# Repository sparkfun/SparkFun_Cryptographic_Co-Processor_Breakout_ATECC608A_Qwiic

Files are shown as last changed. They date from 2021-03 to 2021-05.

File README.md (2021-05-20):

SparkFun Cryptographic Co-Processor Breakout - ATECC608A (Qwiic)
========================================

SparkFun Cryptographic Breakout

[*SparkFun Cryptographic Co-Processor Breakout - ATECC608A (Qwiic) (DEV-18077)*](https://www.sparkfun.com/products/18077)

The SparkFun ATECC608A Cryptographic Co-processor Breakout allows you to add strong security to your IoT node, edge device, or embedded system. This includes asymmetric authentication, symmetric AES-128 encryption/decryption, and much more. As stated above, the ATECC608A has limited Arduino support and the complete datasheet is under NDA with Microchip.

This breakout board includes two Qwiic ports for plug and play functionality. Utilizing our handy Qwiic system, no soldering is required to connect it to the rest of your system. However, we still have broken out 0.1"-spaced pins in case you prefer to use a breadboard. The ATECC608A chip is capable of many cryptographic processes, including, but not limited to:

* Creating and securely storing unique asymmetric key pairs based on Elliptic Curve Cryptography (FIPS186-3).
* AES-128: Encrypt/Decrypt, Galois Field Multiply for GCM
* Creating and verifying 64-byte digital signatures (from 32-bytes of message data).
* Creating a shared secret key on a public channel via Elliptic Curve Diffie-Hellman Algorithm.
* SHA-256 & HMAC Hash including off-chip context save/restore
* Internal high quality FIPS random number generator.
* Embedded in the chip is a 10Kb EEPROM array that can be used for storing keys, certificates, data, consumption logging, and security configurations. Access to the sections of memory can then be restricted and the configuration locked to prevent changes. Each ATECC608A Breakout ships with a guaranteed unique 72-bit serial number and includes several security features to prevent physical attacks on the device itself, or logical attacks on the data transmitted between the device.

A summary datasheet for the ATECC608A is available [here](https://cdn.sparkfun.com/assets/d/5/c/c/a/ATECC608A-CryptoAuthentication-Device-Summary-Data-Sheet-DS40001977B.pdf). The full datasheet is under NDA with Microchip. You will need to contact them for access to the entire datasheet. Meanwhile, the ArduinoATECCX08 Library currently only supports the ATECC608A with SAMD21 Arduino boards

Repository Contents
-------------------

* **/Documentation** - Data sheets, additional product information
* **/Hardware** - Eagle design files (.brd, .sch)
* **/Hardware/Production** - Production panel files (.brd)

Documentation
--------------
* **[ArduinoECCX08 Arduino Library](https://github.com/arduino-libraries/ArduinoECCX08)** - Arduino library for the ATECCX08A.
* **[CryptoAuthLib - ](https://github.com/MicrochipTech/cryptoauthlib)** - Microchip CryptoAuthentication Library (includes Python support).

Product Versions
----------------
* [DEV-18077](https://www.sparkfun.com/products/18077)- Initial Release
* [SPX-15838](https://www.sparkfun.com/products/15838)- SparkX Release

License Information
-------------------

This product is _**open source**_! 

Please review the LICENSE.md file for license information. 

If you have any questions or concerns on licensing, please contact technical support through the [SparkFun forum](https://forum.sparkfun.com/index.php).

Please use, reuse, and modify these files as you see fit. Please maintain attribution to SparkFun Electronics and release any derivative under the same license.

Distributed as-is; no warranty is given.

- Your friends at SparkFun.

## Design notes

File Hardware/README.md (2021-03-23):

SparkFun <PRODUCT NAME> Design Files
=====================================

The .sch and .brd files hare are Eagle CAD schematic and PCB design files from SparkFun Electronics.
A freeware version of Eagle can be found [here](https://www.autodesk.com/products/eagle/free-download).

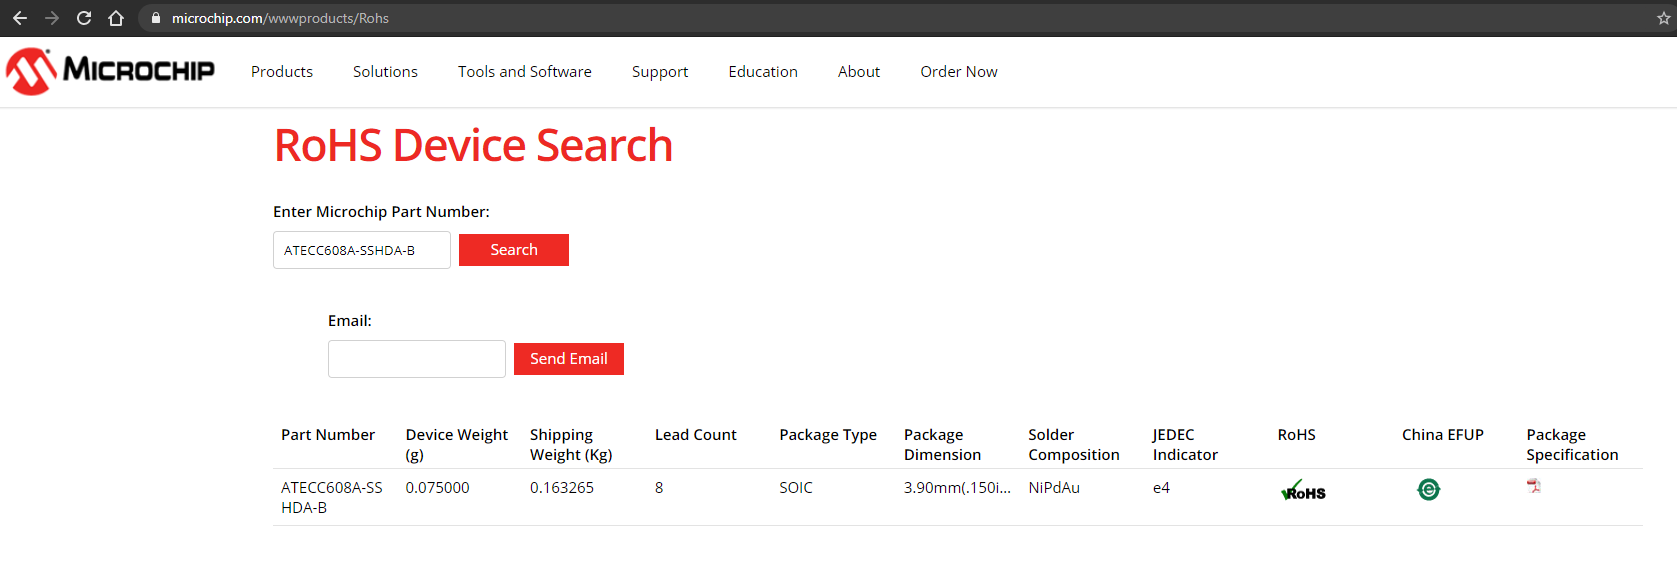
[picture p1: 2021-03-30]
Documentation/RoHS_COMPLIANCE_screenshot_microchip.png

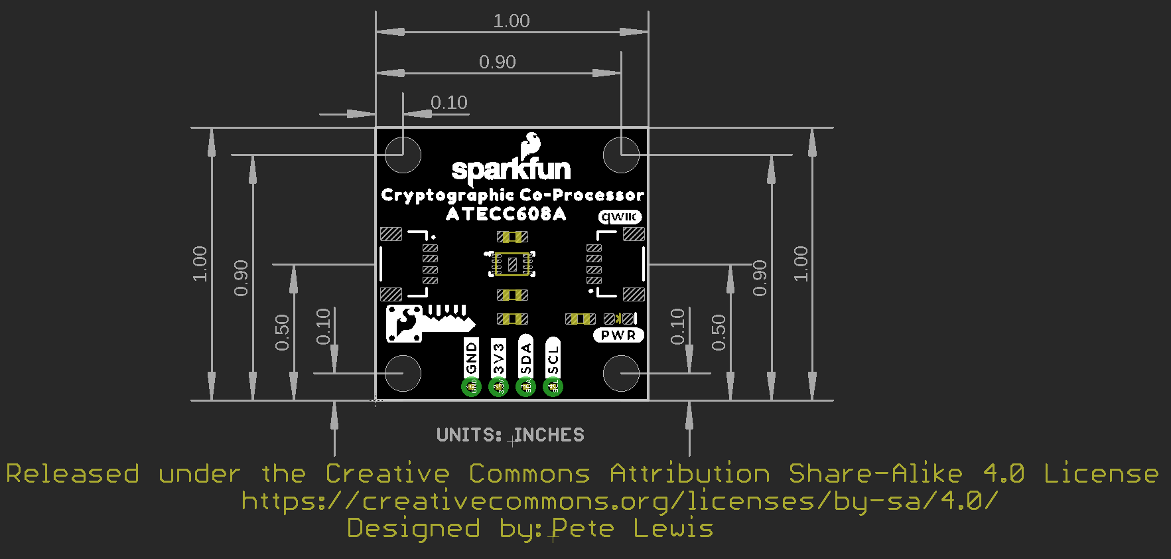
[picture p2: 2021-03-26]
Documentation/SparkFun_Cryptographic_Co-processor_ATECC608A_Dimensions.png

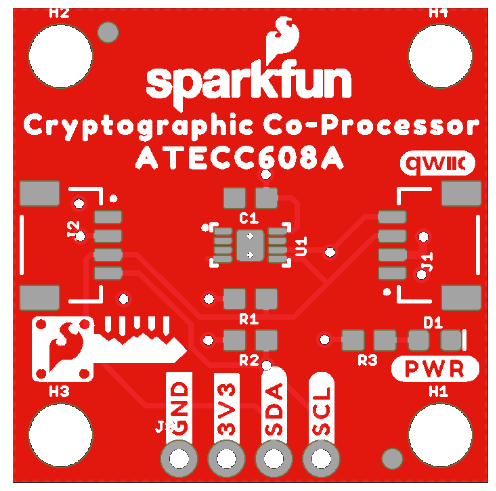
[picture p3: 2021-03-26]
Documentation/board_preview.png

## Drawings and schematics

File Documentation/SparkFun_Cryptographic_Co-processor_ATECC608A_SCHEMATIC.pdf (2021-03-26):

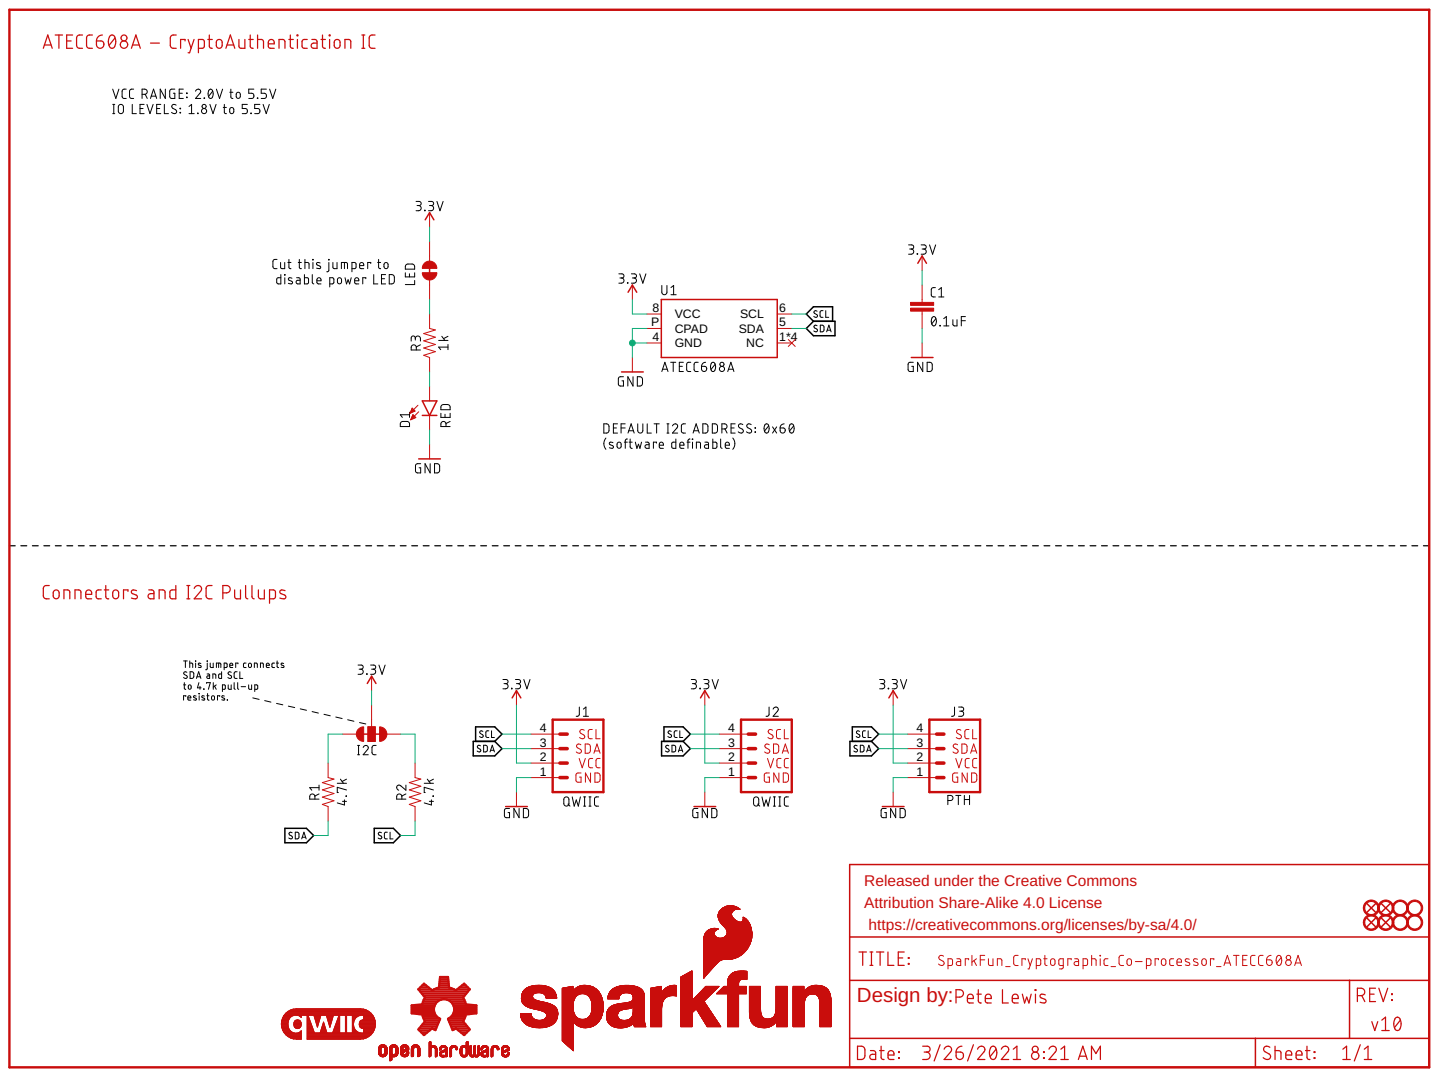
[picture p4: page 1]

Released under the Creative Commons
Attribution Share-Alike 4.0 License
https://creativecommons.org/licenses/by-sa/4.0/

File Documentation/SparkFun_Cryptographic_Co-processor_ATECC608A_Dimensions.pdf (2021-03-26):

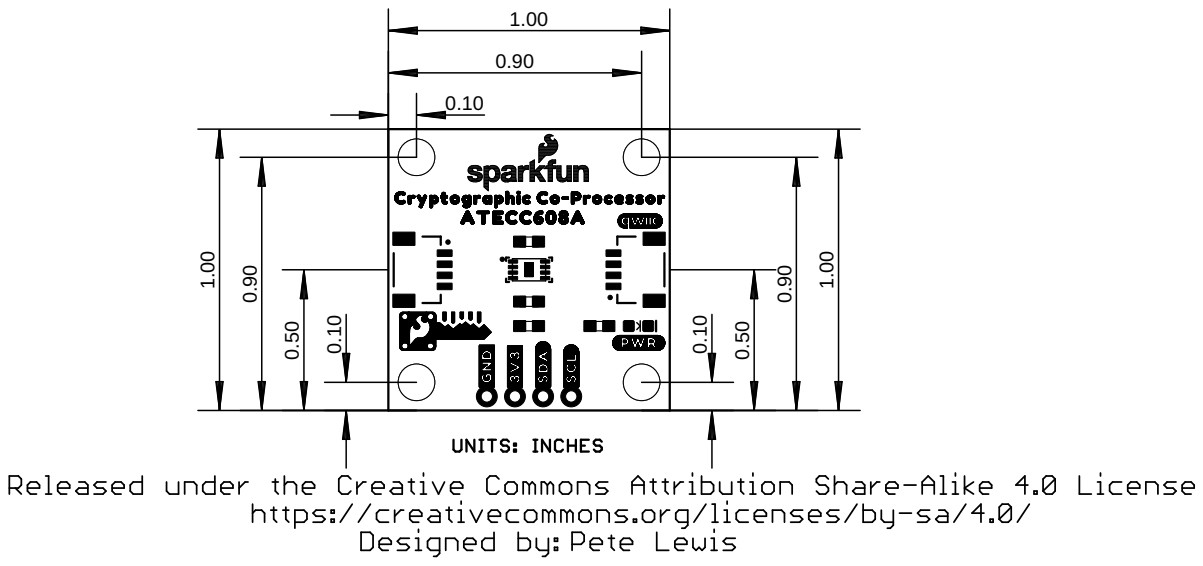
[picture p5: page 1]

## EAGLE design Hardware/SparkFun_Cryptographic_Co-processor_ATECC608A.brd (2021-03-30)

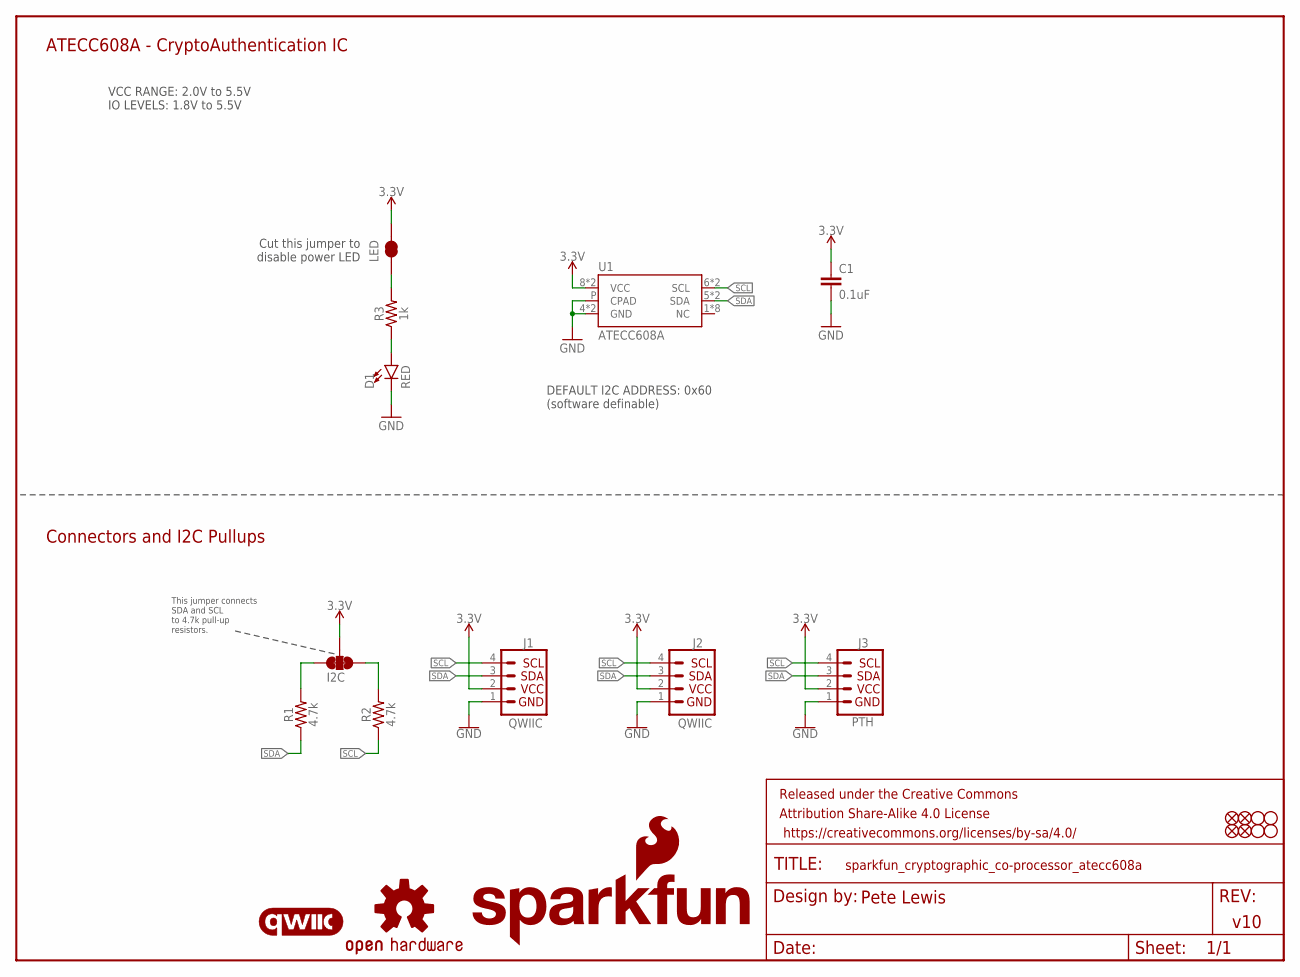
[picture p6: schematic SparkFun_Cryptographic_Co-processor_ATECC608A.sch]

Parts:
C1: 0.1uF; 0603
D1: RED; LED-0603
FD1, FD2, FD3, FD4: FIDUCIAL1X2; FIDUCIAL-1X2
FRAME1: FRAME-LETTER; CREATIVE_COMMONS
H1, H2, H3, H4: STAND-OFF
I2C: JUMPER-SMT_3_2-NC_TRACE_SILK; SMT-JUMPER_3_2-NC_TRACE_SILK
J1, J2: QWIIC; JST04_1MM_RA
J3: PTH; 1X04_NO_SILK
LED: JUMPER-SMT_2_NC_TRACE_SILK; SMT-JUMPER_2_NC_TRACE_SILK
LOGO1: SFE_LOGO_NAME_FLAME.1_INCH; SFE_LOGO_NAME_FLAME_.1
LOGO3: QWIIC_LOGO_4MM; QWIIC_4MM
LOGO4: OSHW-LOGOS; OSHW-LOGO-S
R1, R2: 4.7k; 0603
R3: 1k; 0603
U1: ATECC608A; DUAL_UDFN_2X3MM_SOIC-8

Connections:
3.3V: C1.1, I2C.2, J1.2, J2.2, J3.2, LED.2, U1.8 (VCC), U1.8S (VCC)
GND: C1.2, D1.C, J1.1, J2.1, J3.1, U1.4 (GND), U1.4S (GND), U1.P (CPAD)
unnamed: D1.A, R3.1
unnamed: I2C.3, R1.2
unnamed: I2C.1, R2.2
unnamed: LED.1, R3.2
SCL: J1.4, J2.4, J3.4, R2.1, U1.6 (SCL), U1.6S (SCL)
SDA: J1.3, J2.3, J3.3, R1.1, U1.5 (SDA), U1.5S (SDA)

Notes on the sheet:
This jumper connects SDA and SCL to 4.7k pull-up resistors.
v10
Pete Lewis
ATECC608A - CryptoAuthentication IC
VCC RANGE: 2.0V to 5.5V IO LEVELS: 1.8V to 5.5V
Connectors and I2C Pullups
Cut this jumper to disable power LED
DEFAULT I2C ADDRESS: 0x60 (software definable)

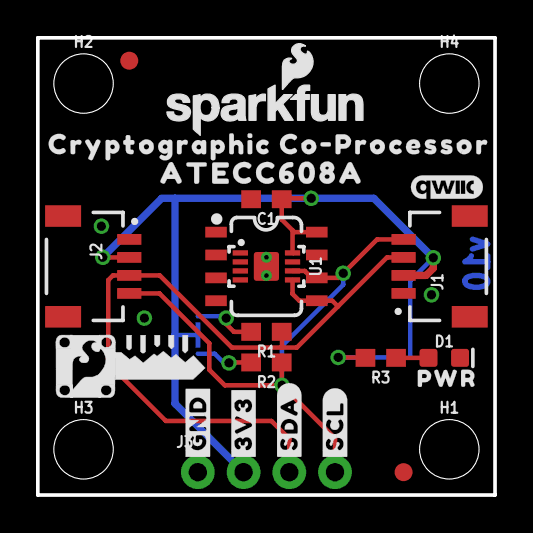
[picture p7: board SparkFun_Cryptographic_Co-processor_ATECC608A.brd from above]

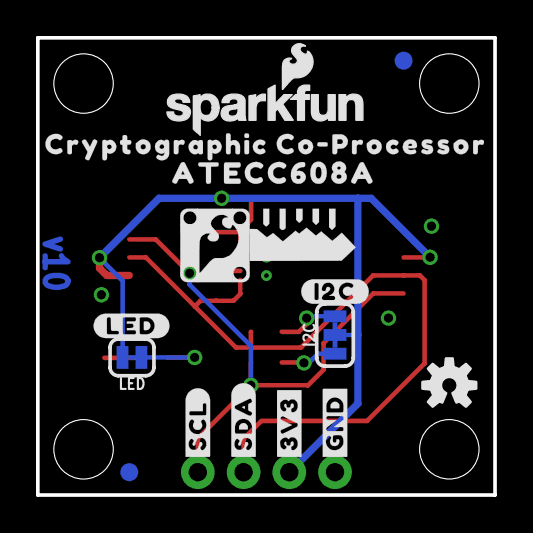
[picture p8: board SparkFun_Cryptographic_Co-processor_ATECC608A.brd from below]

Board: 2 copper layers, 25.4 x 25.4 mm, 41 parts (15 on the bottom side), 8 nets.

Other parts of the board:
LOGO2: SFE_LOGO_NAME_FLAME.1_INCH; SFE_LOGO_NAME_FLAME_.1
U$1: #I2C#0
U$2, U$13: #SCL#0
U$3: #LED#0
U$4, U$17: #SDA#0
U$5, U$7: ATECC608A0
U$6, U$20: #3V3#0
U$8: CRYPTO_COPROCESSOR_LOGO_LARGE
U$9, U$19: CRYPTOGRAPHIC_CO#PROCESSOR0
U$10: CRYPTO_COPROCESSOR_LOGO_SMALL
U$11: PWR0
U$21, U$23: #GND#0

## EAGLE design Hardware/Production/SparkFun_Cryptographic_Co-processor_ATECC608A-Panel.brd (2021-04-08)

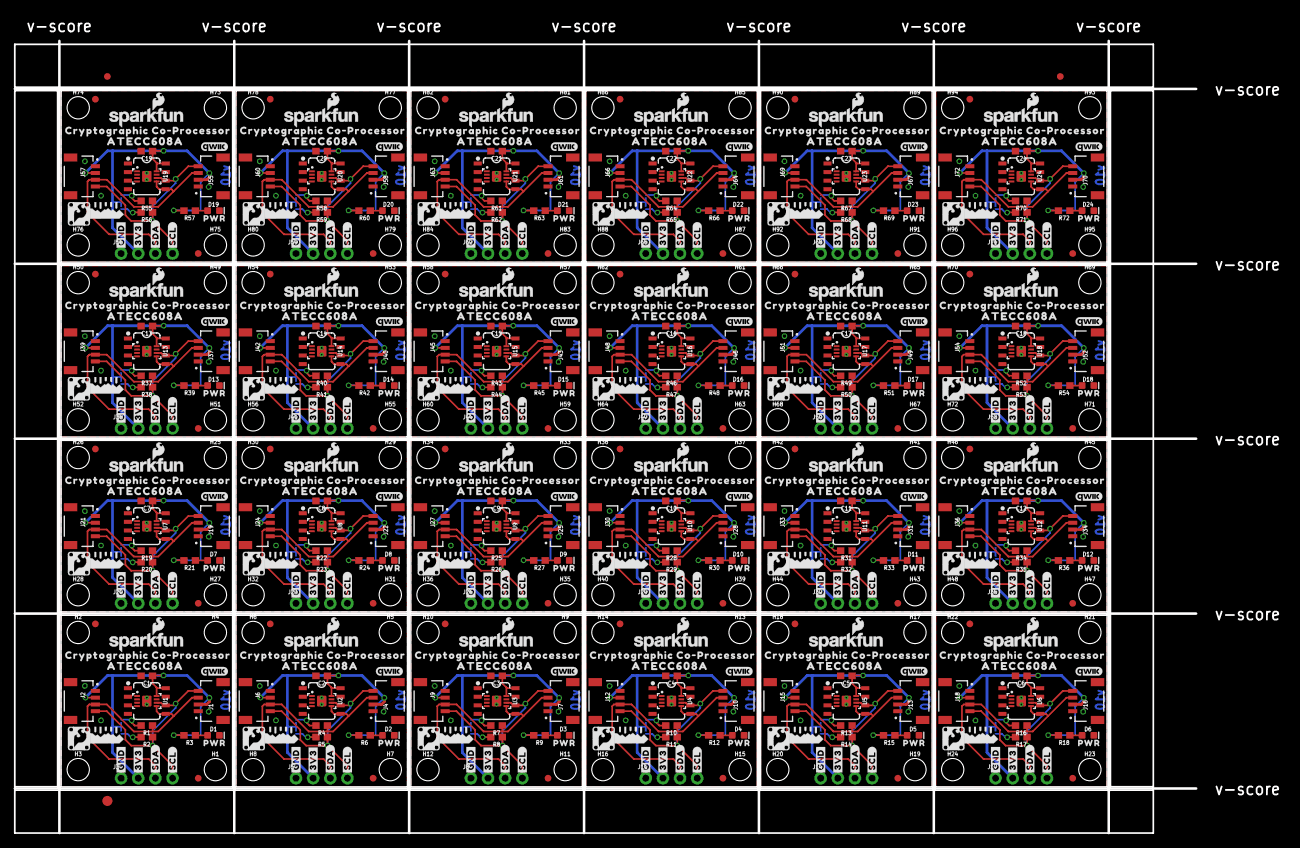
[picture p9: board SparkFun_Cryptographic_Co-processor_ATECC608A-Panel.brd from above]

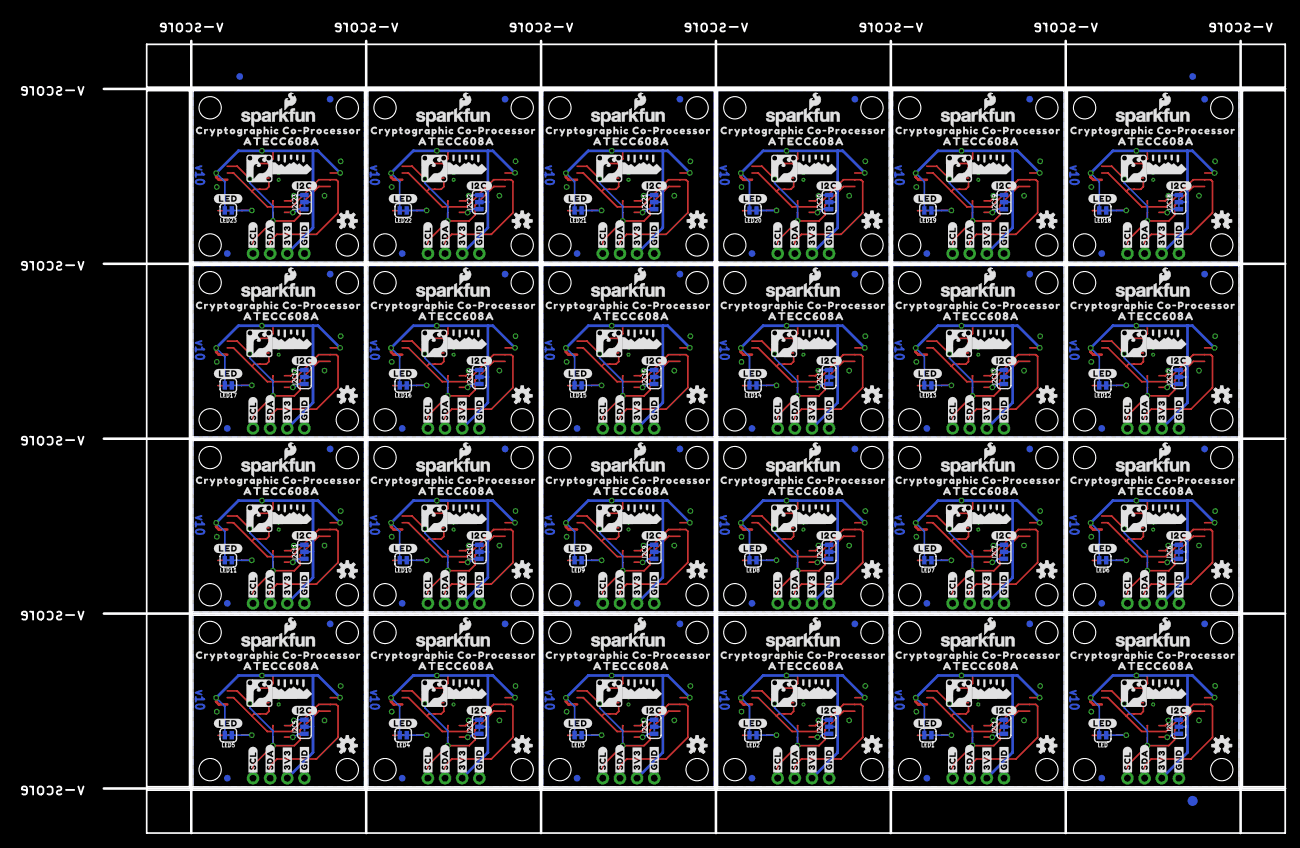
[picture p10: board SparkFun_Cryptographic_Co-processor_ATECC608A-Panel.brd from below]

Board: 2 copper layers, 175.0 x 117.3 mm, 966 parts (363 on the bottom side), 192 nets.

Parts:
C1, C2, C3, C4, C5, C6, C7, C8, C9, C10, C11, C12, C13, C14, C15, C16, C17, C18, C19, C20, C21, C22, C23, C24: 0.1uF; 0603
D1, D2, D3, D4, D5, D6, D7, D8, D9, D10, D11, D12, D13, D14, D15, D16, D17, D18, D19, D20, D21, D22, D23, D24: RED; LED-0603
E$1, E$2, E$3, E$4: FIDUCIAL-1X2
E$5, E$6: FIDUCIAL-1.5X3
FD1, FD2, FD3, FD4, FD5, FD6, FD7, FD8, FD9, FD10, FD11, FD12, FD13, FD14, FD15, FD16, FD17, FD18, FD19, FD20, FD21, FD22, FD23, FD24, FD25, FD26, FD27, FD28, FD29, FD30, FD31, FD32, FD33, FD34, FD35, FD36, FD37, FD38, FD39, FD40, FD41, FD42, FD43, FD44, FD45, FD46, FD47, FD48, FD49, FD50, FD51, FD52, FD53, FD54, FD55, FD56, FD57, FD58, FD59, FD60, FD61, FD62, FD63, FD64, FD65, FD66, FD67, FD68, FD69, FD70, FD71, FD72, FD73, FD74, FD75, FD76, FD77, FD78, FD79, FD80, FD81, FD82, FD83, FD84, FD85, FD86, FD87, FD88, FD89, FD90, FD91, FD92, FD93, FD94, FD95, FD96: FIDUCIAL1X2; FIDUCIAL-1X2
H1, H2, H3, H4, H5, H6, H7, H8, H9, H10, H11, H12, H13, H14, H15, H16, H17, H18, H19, H20, H21, H22, H23, H24, H25, H26, H27, H28, H29, H30, H31, H32, H33, H34, H35, H36, H37, H38, H39, H40, H41, H42, H43, H44, H45, H46, H47, H48, H49, H50, H51, H52, H53, H54, H55, H56, H57, H58, H59, H60, H61, H62, H63, H64, H65, H66, H67, H68, H69, H70, H71, H72, H73, H74, H75, H76, H77, H78, H79, H80, H81, H82, H83, H84, H85, H86, H87, H88, H89, H90, H91, H92, H93, H94, H95, H96: STAND-OFF
I2C, I2C1, I2C2, I2C3, I2C4, I2C5, I2C6, I2C7, I2C8, I2C9, I2C10, I2C11, I2C12, I2C13, I2C14, I2C15, I2C16, I2C17, I2C18, I2C19, I2C20, I2C21, I2C22, I2C23: SMT-JUMPER_3_2-NC_TRACE_SILK
J1, J2, J4, J6, J7, J9, J10, J12, J13, J15, J16, J18, J19, J21, J22, J24, J25, J27, J28, J30, J31, J33, J34, J36, J37, J39, J40, J42, J43, J45, J46, J48, J49, J51, J52, J54, J55, J57, J58, J60, J61, J63, J64, J66, J67, J69, J70, J72: QWIIC; JST04_1MM_RA
J3, J5, J8, J11, J14, J17, J20, J23, J26, J29, J32, J35, J38, J41, J44, J47, J50, J53, J56, J59, J62, J65, J68, J71: PTH; 1X04_NO_SILK
LED, LED1, LED2, LED3, LED4, LED5, LED6, LED7, LED8, LED9, LED10, LED11, LED12, LED13, LED14, LED15, LED16, LED17, LED18, LED19, LED20, LED21, LED22, LED23: SMT-JUMPER_2_NC_TRACE_SILK
LOGO1, LOGO2, LOGO6, LOGO7, LOGO10, LOGO11, LOGO14, LOGO15, LOGO18, LOGO19, LOGO22, LOGO23, LOGO26, LOGO27, LOGO30, LOGO31, LOGO34, LOGO35, LOGO38, LOGO39, LOGO42, LOGO43, LOGO46, LOGO47, LOGO50, LOGO51, LOGO54, LOGO55, LOGO58, LOGO59, LOGO62, LOGO63, LOGO66, LOGO67, LOGO70, LOGO71, LOGO74, LOGO75, LOGO78, LOGO79, LOGO82, LOGO83, LOGO86, LOGO87, LOGO90, LOGO91, LOGO94, LOGO95: SFE_LOGO_NAME_FLAME.1_INCH; SFE_LOGO_NAME_FLAME_.1
LOGO3, LOGO8, LOGO12, LOGO16, LOGO20, LOGO24, LOGO28, LOGO32, LOGO36, LOGO40, LOGO44, LOGO48, LOGO52, LOGO56, LOGO60, LOGO64, LOGO68, LOGO72, LOGO76, LOGO80, LOGO84, LOGO88, LOGO92, LOGO96: QWIIC_LOGO_4MM; QWIIC_4MM
LOGO4, LOGO5, LOGO9, LOGO13, LOGO17, LOGO21, LOGO25, LOGO29, LOGO33, LOGO37, LOGO41, LOGO45, LOGO49, LOGO53, LOGO57, LOGO61, LOGO65, LOGO69, LOGO73, LOGO77, LOGO81, LOGO85, LOGO89, LOGO93: OSHW-LOGOS; OSHW-LOGO-S
R1, R2, R4, R5, R7, R8, R10, R11, R13, R14, R16, R17, R19, R20, R22, R23, R25, R26, R28, R29, R31, R32, R34, R35, R37, R38, R40, R41, R43, R44, R46, R47, R49, R50, R52, R53, R55, R56, R58, R59, R61, R62, R64, R65, R67, R68, R70, R71: 4.7k; 0603
R3, R6, R9, R12, R15, R18, R21, R24, R27, R30, R33, R36, R39, R42, R45, R48, R51, R54, R57, R60, R63, R66, R69, R72: 1k; 0603
U1, U2, U3, U4, U5, U6, U7, U8, U9, U10, U11, U12, U13, U14, U15, U16, U17, U18, U19, U20, U21, U22, U23, U24: ATECC608A; DUAL_UDFN_2X3MM_SOIC-8
U$1, U$29, U$46, U$63, U$80, U$97, U$114, U$131, U$148, U$165, U$182, U$199, U$216, U$233, U$250, U$267, U$284, U$301, U$318, U$335, U$352, U$369, U$386, U$403: #I2C#0
U$2, U$13, U$15, U$24, U$37, U$41, U$54, U$58, U$71, U$75, U$88, U$92, U$105, U$109, U$122, U$126, U$139, U$143, U$156, U$160, U$173, U$177, U$190, U$194, U$207, U$211, U$224, U$228, U$241, U$245, U$258, U$262, U$275, U$279, U$292, U$296, U$309, U$313, U$326, U$330, U$343, U$347, U$360, U$364, U$377, U$381, U$394, U$398: #SCL#0
U$3, U$28, U$45, U$62, U$79, U$96, U$113, U$130, U$147, U$164, U$181, U$198, U$215, U$232, U$249, U$266, U$283, U$300, U$317, U$334, U$351, U$368, U$385, U$402: #LED#0
U$4, U$16, U$17, U$25, U$38, U$42, U$55, U$59, U$72, U$76, U$89, U$93, U$106, U$110, U$123, U$127, U$140, U$144, U$157, U$161, U$174, U$178, U$191, U$195, U$208, U$212, U$225, U$229, U$242, U$246, U$259, U$263, U$276, U$280, U$293, U$297, U$310, U$314, U$327, U$331, U$344, U$348, U$361, U$365, U$378, U$382, U$395, U$399: #SDA#0
U$5, U$7, U$30, U$31, U$47, U$48, U$64, U$65, U$81, U$82, U$98, U$99, U$115, U$116, U$132, U$133, U$149, U$150, U$166, U$167, U$183, U$184, U$200, U$201, U$217, U$218, U$234, U$235, U$251, U$252, U$268, U$269, U$285, U$286, U$302, U$303, U$319, U$320, U$336, U$337, U$353, U$354, U$370, U$371, U$387, U$388, U$404, U$405: ATECC608A0
U$6, U$18, U$20, U$26, U$39, U$43, U$56, U$60, U$73, U$77, U$90, U$94, U$107, U$111, U$124, U$128, U$141, U$145, U$158, U$162, U$175, U$179, U$192, U$196, U$209, U$213, U$226, U$230, U$243, U$247, U$260, U$264, U$277, U$281, U$294, U$298, U$311, U$315, U$328, U$332, U$345, U$349, U$362, U$366, U$379, U$383, U$396, U$400: #3V3#0
U$8, U$32, U$49, U$66, U$83, U$100, U$117, U$134, U$151, U$168, U$185, U$202, U$219, U$236, U$253, U$270, U$287, U$304, U$321, U$338, U$355, U$372, U$389, U$406: CRYPTO_COPROCESSOR_LOGO_LARGE
U$9, U$12, U$14, U$19, U$35, U$36, U$52, U$53, U$69, U$70, U$86, U$87, U$103, U$104, U$120, U$121, U$137, U$138, U$154, U$155, U$171, U$172, U$188, U$189, U$205, U$206, U$222, U$223, U$239, U$240, U$256, U$257, U$273, U$274, U$290, U$291, U$307, U$308, U$324, U$325, U$341, U$342, U$358, U$359, U$375, U$376, U$392, U$393: CRYPTOGRAPHIC_CO#PROCESSOR0
U$10, U$33, U$50, U$67, U$84, U$101, U$118, U$135, U$152, U$169, U$186, U$203, U$220, U$237, U$254, U$271, U$288, U$305, U$322, U$339, U$356, U$373, U$390, U$407: CRYPTO_COPROCESSOR_LOGO_SMALL
U$11, U$34, U$51, U$68, U$85, U$102, U$119, U$136, U$153, U$170, U$187, U$204, U$221, U$238, U$255, U$272, U$289, U$306, U$323, U$340, U$357, U$374, U$391, U$408: PWR0
U$21, U$22, U$23, U$27, U$40, U$44, U$57, U$61, U$74, U$78, U$91, U$95, U$108, U$112, U$125, U$129, U$142, U$146, U$159, U$163, U$176, U$180, U$193, U$197, U$210, U$214, U$227, U$231, U$244, U$248, U$261, U$265, U$278, U$282, U$295, U$299, U$312, U$316, U$329, U$333, U$346, U$350, U$363, U$367, U$380, U$384, U$397, U$401: #GND#0

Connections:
3.3V: C1.1, I2C.2, J1.2, J2.2, J3.2, LED.2, U1.8, U1.8S
3.3V1: C2.1, I2C1.2, J4.2, J5.2, J6.2, LED1.2, U2.8, U2.8S
3.3V2: C3.1, I2C2.2, J7.2, J8.2, J9.2, LED2.2, U3.8, U3.8S
3.3V3: C4.1, I2C3.2, J10.2, J11.2, J12.2, LED3.2, U4.8, U4.8S
3.3V4: C5.1, I2C4.2, J13.2, J14.2, J15.2, LED4.2, U5.8, U5.8S
3.3V5: C6.1, I2C5.2, J16.2, J17.2, J18.2, LED5.2, U6.8, U6.8S
3.3V6: C7.1, I2C6.2, J19.2, J20.2, J21.2, LED6.2, U7.8, U7.8S
3.3V7: C8.1, I2C7.2, J22.2, J23.2, J24.2, LED7.2, U8.8, U8.8S
3.3V8: C9.1, I2C8.2, J25.2, J26.2, J27.2, LED8.2, U9.8, U9.8S
3.3V9: C10.1, I2C9.2, J28.2, J29.2, J30.2, LED9.2, U10.8, U10.8S
3.3V10: C11.1, I2C10.2, J31.2, J32.2, J33.2, LED10.2, U11.8, U11.8S
3.3V11: C12.1, I2C11.2, J34.2, J35.2, J36.2, LED11.2, U12.8, U12.8S
3.3V12: C13.1, I2C12.2, J37.2, J38.2, J39.2, LED12.2, U13.8, U13.8S
3.3V13: C14.1, I2C13.2, J40.2, J41.2, J42.2, LED13.2, U14.8, U14.8S
3.3V14: C15.1, I2C14.2, J43.2, J44.2, J45.2, LED14.2, U15.8, U15.8S
3.3V15: C16.1, I2C15.2, J46.2, J47.2, J48.2, LED15.2, U16.8, U16.8S
3.3V16: C17.1, I2C16.2, J49.2, J50.2, J51.2, LED16.2, U17.8, U17.8S
3.3V17: C18.1, I2C17.2, J52.2, J53.2, J54.2, LED17.2, U18.8, U18.8S
3.3V18: C19.1, I2C18.2, J55.2, J56.2, J57.2, LED18.2, U19.8, U19.8S
3.3V19: C20.1, I2C19.2, J58.2, J59.2, J60.2, LED19.2, U20.8, U20.8S
3.3V20: C21.1, I2C20.2, J61.2, J62.2, J63.2, LED20.2, U21.8, U21.8S
3.3V21: C22.1, I2C21.2, J64.2, J65.2, J66.2, LED21.2, U22.8, U22.8S
3.3V22: C23.1, I2C22.2, J67.2, J68.2, J69.2, LED22.2, U23.8, U23.8S
3.3V23: C24.1, I2C23.2, J70.2, J71.2, J72.2, LED23.2, U24.8, U24.8S
GND: C1.2, D1.C, J1.1, J2.1, J3.1, U1.4, U1.4S, U1.P
GND1: C2.2, D2.C, J4.1, J5.1, J6.1, U2.4, U2.4S, U2.P
GND2: C3.2, D3.C, J7.1, J8.1, J9.1, U3.4, U3.4S, U3.P
GND3: C4.2, D4.C, J10.1, J11.1, J12.1, U4.4, U4.4S, U4.P
GND4: C5.2, D5.C, J13.1, J14.1, J15.1, U5.4, U5.4S, U5.P
GND5: C6.2, D6.C, J16.1, J17.1, J18.1, U6.4, U6.4S, U6.P
GND6: C7.2, D7.C, J19.1, J20.1, J21.1, U7.4, U7.4S, U7.P
GND7: C8.2, D8.C, J22.1, J23.1, J24.1, U8.4, U8.4S, U8.P
GND8: C9.2, D9.C, J25.1, J26.1, J27.1, U9.4, U9.4S, U9.P
GND9: C10.2, D10.C, J28.1, J29.1, J30.1, U10.4, U10.4S, U10.P
GND10: C11.2, D11.C, J31.1, J32.1, J33.1, U11.4, U11.4S, U11.P
GND11: C12.2, D12.C, J34.1, J35.1, J36.1, U12.4, U12.4S, U12.P
GND12: C13.2, D13.C, J37.1, J38.1, J39.1, U13.4, U13.4S, U13.P
GND13: C14.2, D14.C, J40.1, J41.1, J42.1, U14.4, U14.4S, U14.P
GND14: C15.2, D15.C, J43.1, J44.1, J45.1, U15.4, U15.4S, U15.P
GND15: C16.2, D16.C, J46.1, J47.1, J48.1, U16.4, U16.4S, U16.P
GND16: C17.2, D17.C, J49.1, J50.1, J51.1, U17.4, U17.4S, U17.P
GND17: C18.2, D18.C, J52.1, J53.1, J54.1, U18.4, U18.4S, U18.P
GND18: C19.2, D19.C, J55.1, J56.1, J57.1, U19.4, U19.4S, U19.P
GND19: C20.2, D20.C, J58.1, J59.1, J60.1, U20.4, U20.4S, U20.P
GND20: C21.2, D21.C, J61.1, J62.1, J63.1, U21.4, U21.4S, U21.P
GND21: C22.2, D22.C, J64.1, J65.1, J66.1, U22.4, U22.4S, U22.P
GND22: C23.2, D23.C, J67.1, J68.1, J69.1, U23.4, U23.4S, U23.P
GND23: C24.2, D24.C, J70.1, J71.1, J72.1, U24.4, U24.4S, U24.P
unnamed: I2C1.3, R4.2
unnamed: I2C1.1, R5.2
unnamed: D1.A, R3.1
unnamed: I2C.3, R1.2
unnamed: I2C.1, R2.2
unnamed: D2.A, R6.1
unnamed: LED.1, R3.2
unnamed: LED1.1, R6.2
unnamed: I2C2.3, R7.2
unnamed: I2C2.1, R8.2
unnamed: D3.A, R9.1
unnamed: LED2.1, R9.2
unnamed: I2C3.3, R10.2
unnamed: I2C3.1, R11.2
unnamed: D4.A, R12.1
unnamed: LED3.1, R12.2
unnamed: I2C4.3, R13.2
unnamed: I2C4.1, R14.2
unnamed: D5.A, R15.1
unnamed: LED4.1, R15.2
unnamed: I2C5.3, R16.2
unnamed: I2C5.1, R17.2
unnamed: D6.A, R18.1
unnamed: LED5.1, R18.2
unnamed: I2C6.3, R19.2
unnamed: I2C6.1, R20.2
unnamed: D7.A, R21.1
unnamed: LED6.1, R21.2
unnamed: I2C7.3, R22.2
unnamed: I2C7.1, R23.2
unnamed: D8.A, R24.1
unnamed: LED7.1, R24.2
unnamed: I2C8.3, R25.2
unnamed: I2C8.1, R26.2
unnamed: D9.A, R27.1
unnamed: LED8.1, R27.2
unnamed: I2C9.3, R28.2
unnamed: I2C9.1, R29.2
unnamed: D10.A, R30.1
unnamed: LED9.1, R30.2
unnamed: I2C10.3, R31.2
unnamed: I2C10.1, R32.2
unnamed: D11.A, R33.1
unnamed: LED10.1, R33.2
unnamed: I2C11.3, R34.2
unnamed: I2C11.1, R35.2
unnamed: D12.A, R36.1
unnamed: LED11.1, R36.2
unnamed: I2C12.3, R37.2
unnamed: I2C12.1, R38.2
unnamed: D13.A, R39.1
unnamed: LED12.1, R39.2
unnamed: I2C13.3, R40.2
unnamed: I2C13.1, R41.2
unnamed: D14.A, R42.1
unnamed: LED13.1, R42.2
unnamed: I2C14.3, R43.2
unnamed: I2C14.1, R44.2
unnamed: D15.A, R45.1
unnamed: LED14.1, R45.2
unnamed: I2C15.3, R46.2
unnamed: I2C15.1, R47.2
unnamed: D16.A, R48.1
unnamed: LED15.1, R48.2
unnamed: I2C16.3, R49.2
unnamed: I2C16.1, R50.2
unnamed: D17.A, R51.1
unnamed: LED16.1, R51.2
unnamed: I2C17.3, R52.2
unnamed: I2C17.1, R53.2
unnamed: D18.A, R54.1
unnamed: LED17.1, R54.2
unnamed: I2C18.3, R55.2
unnamed: I2C18.1, R56.2
unnamed: D19.A, R57.1
unnamed: LED18.1, R57.2
unnamed: I2C19.3, R58.2
unnamed: I2C19.1, R59.2
unnamed: D20.A, R60.1
unnamed: LED19.1, R60.2
unnamed: I2C20.3, R61.2
unnamed: I2C20.1, R62.2
unnamed: D21.A, R63.1
unnamed: LED20.1, R63.2
unnamed: I2C21.3, R64.2
unnamed: I2C21.1, R65.2
unnamed: D22.A, R66.1
unnamed: LED21.1, R66.2
unnamed: I2C22.3, R67.2
unnamed: I2C22.1, R68.2
unnamed: D23.A, R69.1
unnamed: LED22.1, R69.2
unnamed: I2C23.3, R70.2
unnamed: I2C23.1, R71.2
unnamed: D24.A, R72.1
unnamed: LED23.1, R72.2
SCL: J1.4, J2.4, J3.4, R2.1, U1.6, U1.6S
SCL1: J4.4, J5.4, J6.4, R5.1, U2.6, U2.6S
SCL2: J7.4, J8.4, J9.4, R8.1, U3.6, U3.6S
SCL3: J10.4, J11.4, J12.4, R11.1, U4.6, U4.6S
SCL4: J13.4, J14.4, J15.4, R14.1, U5.6, U5.6S
SCL5: J16.4, J17.4, J18.4, R17.1, U6.6, U6.6S
SCL6: J19.4, J20.4, J21.4, R20.1, U7.6, U7.6S
SCL7: J22.4, J23.4, J24.4, R23.1, U8.6, U8.6S
SCL8: J25.4, J26.4, J27.4, R26.1, U9.6, U9.6S
SCL9: J28.4, J29.4, J30.4, R29.1, U10.6, U10.6S
SCL10: J31.4, J32.4, J33.4, R32.1, U11.6, U11.6S
SCL11: J34.4, J35.4, J36.4, R35.1, U12.6, U12.6S
SCL12: J37.4, J38.4, J39.4, R38.1, U13.6, U13.6S
SCL13: J40.4, J41.4, J42.4, R41.1, U14.6, U14.6S
SCL14: J43.4, J44.4, J45.4, R44.1, U15.6, U15.6S
SCL15: J46.4, J47.4, J48.4, R47.1, U16.6, U16.6S
SCL16: J49.4, J50.4, J51.4, R50.1, U17.6, U17.6S
SCL17: J52.4, J53.4, J54.4, R53.1, U18.6, U18.6S
SCL18: J55.4, J56.4, J57.4, R56.1, U19.6, U19.6S
SCL19: J58.4, J59.4, J60.4, R59.1, U20.6, U20.6S
SCL20: J61.4, J62.4, J63.4, R62.1, U21.6, U21.6S
SCL21: J64.4, J65.4, J66.4, R65.1, U22.6, U22.6S
SCL22: J67.4, J68.4, J69.4, R68.1, U23.6, U23.6S
SCL23: J70.4, J71.4, J72.4, R71.1, U24.6, U24.6S
SDA: J1.3, J2.3, J3.3, R1.1, U1.5, U1.5S
SDA1: J4.3, J5.3, J6.3, R4.1, U2.5, U2.5S
SDA2: J7.3, J8.3, J9.3, R7.1, U3.5, U3.5S
SDA3: J10.3, J11.3, J12.3, R10.1, U4.5, U4.5S
SDA4: J13.3, J14.3, J15.3, R13.1, U5.5, U5.5S
SDA5: J16.3, J17.3, J18.3, R16.1, U6.5, U6.5S
SDA6: J19.3, J20.3, J21.3, R19.1, U7.5, U7.5S
SDA7: J22.3, J23.3, J24.3, R22.1, U8.5, U8.5S
SDA8: J25.3, J26.3, J27.3, R25.1, U9.5, U9.5S
SDA9: J28.3, J29.3, J30.3, R28.1, U10.5, U10.5S
SDA10: J31.3, J32.3, J33.3, R31.1, U11.5, U11.5S
SDA11: J34.3, J35.3, J36.3, R34.1, U12.5, U12.5S
SDA12: J37.3, J38.3, J39.3, R37.1, U13.5, U13.5S
SDA13: J40.3, J41.3, J42.3, R40.1, U14.5, U14.5S
SDA14: J43.3, J44.3, J45.3, R43.1, U15.5, U15.5S
SDA15: J46.3, J47.3, J48.3, R46.1, U16.5, U16.5S
SDA16: J49.3, J50.3, J51.3, R49.1, U17.5, U17.5S
SDA17: J52.3, J53.3, J54.3, R52.1, U18.5, U18.5S
SDA18: J55.3, J56.3, J57.3, R55.1, U19.5, U19.5S
SDA19: J58.3, J59.3, J60.3, R58.1, U20.5, U20.5S
SDA20: J61.3, J62.3, J63.3, R61.1, U21.5, U21.5S
SDA21: J64.3, J65.3, J66.3, R64.1, U22.5, U22.5S
SDA22: J67.3, J68.3, J69.3, R67.1, U23.5, U23.5S
SDA23: J70.3, J71.3, J72.3, R70.1, U24.5, U24.5S

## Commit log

2021-03-23 Layout done - w/vector logos and buzzards
    [SparkFun_Cryptographic_Co-processor_ATECC608A.brd, SparkFun_Cryptographic_Co-processor_ATECC608A.sch]
2021-03-26 eng 1st run checklist stuff
    -added qwiic logo as device so it has logo in SCH
    -update vector font to "non-legacy"
    -cleaned up assembly sheet view attribute placement
    -IC datasheet (summary only)
    -measures updated, PNG and PDF files created.
    -Exported SCH as PDF in docs
    [SparkFun_Cryptographic_Co-processor_ATECC608A.brd, SparkFun_Cryptographic_Co-processor_ATECC608A.sch]
2021-03-26 Manufacturing tool color set and preview PNG
    [SparkFun_Cryptographic_Co-processor_ATECC608A.brd]
2021-03-29 Move to dual-type package (UDFN and SOIC)
    [SparkFun_Cryptographic_Co-processor_ATECC608A.brd, SparkFun_Cryptographic_Co-processor_ATECC608A.sch]
2021-03-30 Added PROD_ID to atecc608a (soic-8 package)
    -also added RoHS documentation for the IC.
    [SparkFun_Cryptographic_Co-processor_ATECC608A.brd, SparkFun_Cryptographic_Co-processor_ATECC608A.sch]
2021-03-30 PWR to text only buzzard (was previously inverted bubble)
    [SparkFun_Cryptographic_Co-processor_ATECC608A.brd]
2021-04-08 Production panel BRD and Gerbers (v10)
    [SparkFun_Cryptographic_Co-processor_ATECC608A-Panel.brd]

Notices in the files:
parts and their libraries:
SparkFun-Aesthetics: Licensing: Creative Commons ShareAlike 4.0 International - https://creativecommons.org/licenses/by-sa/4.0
